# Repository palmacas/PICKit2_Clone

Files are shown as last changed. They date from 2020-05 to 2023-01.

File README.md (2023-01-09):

# PICKit2 Clone

PICKit2Clone

This is a DIY version (clone) of the well known Microchip's PICKit2 programmer, with an additional ZIF socket. The repository contains the editable EAGLE files and the scheme on PDF. In addition, the ZIF_Distribution folder contains images with the ICs and jumpers distribution on the ZIF socket depending on the PIC type.

---
More information:  
[PICKit 2 Clone Zócalo ZIF [Spanish]](https://palmacas.com/pickit-2-clone-zocalo-zif/)  
[Zócalo ZIF – PICKit 2 y PICKit 3 [Spanish]](https://palmacas.com/zocalo-zif-pickit-2-y-pickit-3/)  
[Distribución de Zócalo ZIF [Spanish]](https://palmacas.com/distribucion-zocalo-zif/)  
[PICKit 2 Clone ICSP [Spanish]](https://palmacas.com/pickit-2-clone-icsp/)

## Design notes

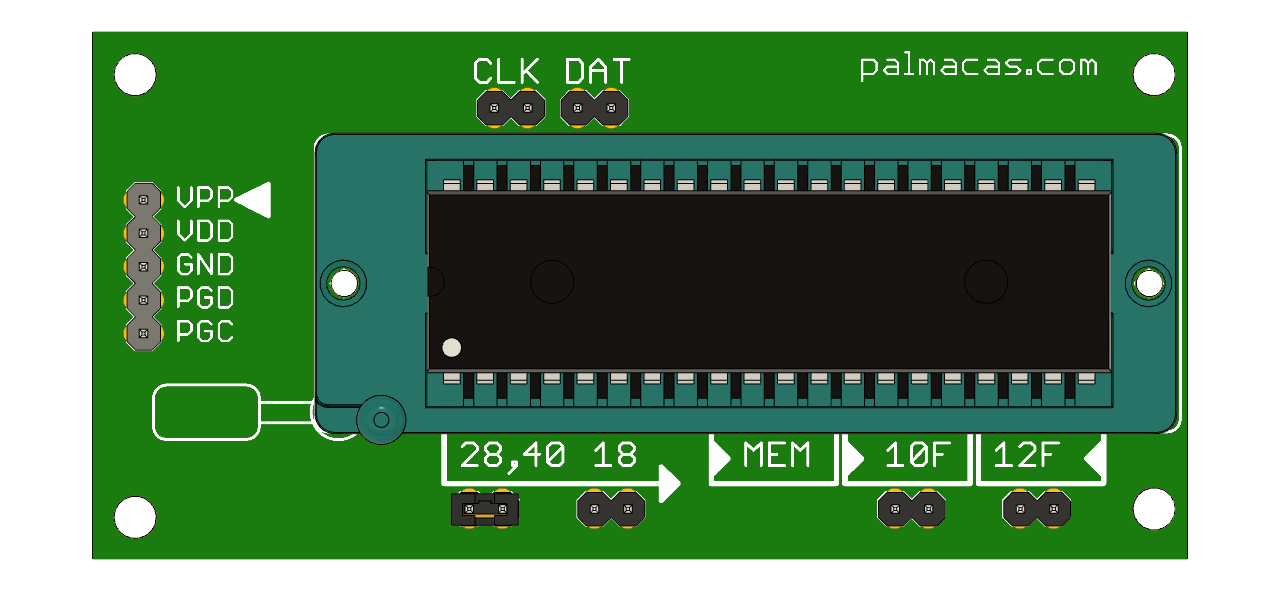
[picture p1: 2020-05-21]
ZIF_Distribution/40pin sdPIC.png

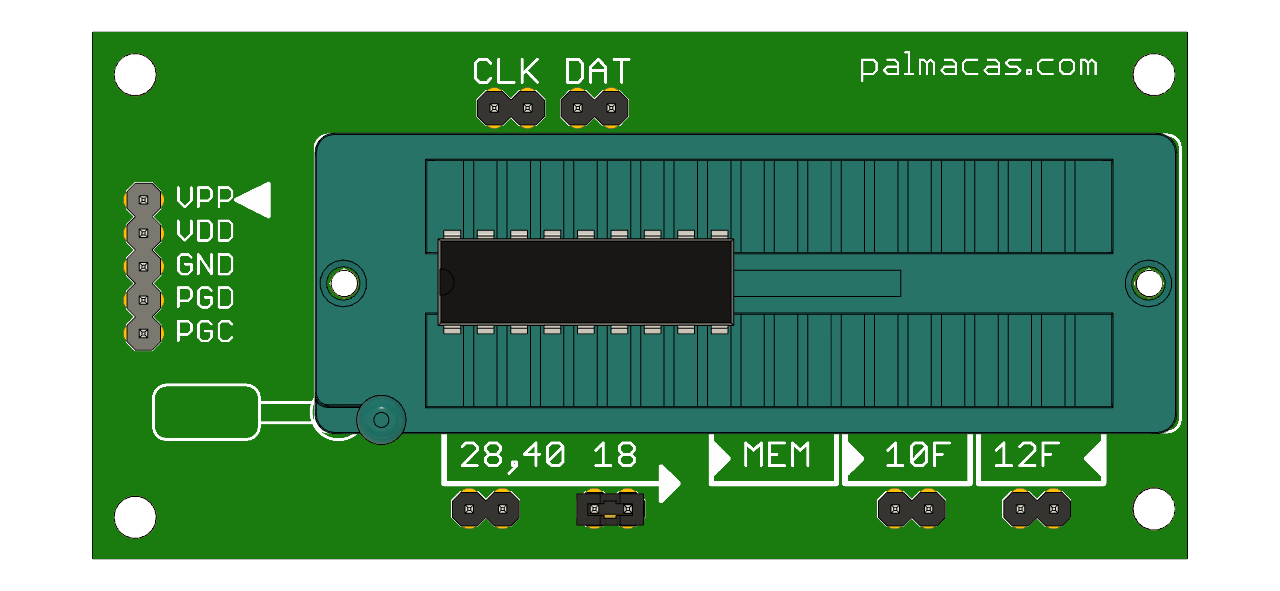
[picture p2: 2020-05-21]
ZIF_Distribution/18pin PIC.png

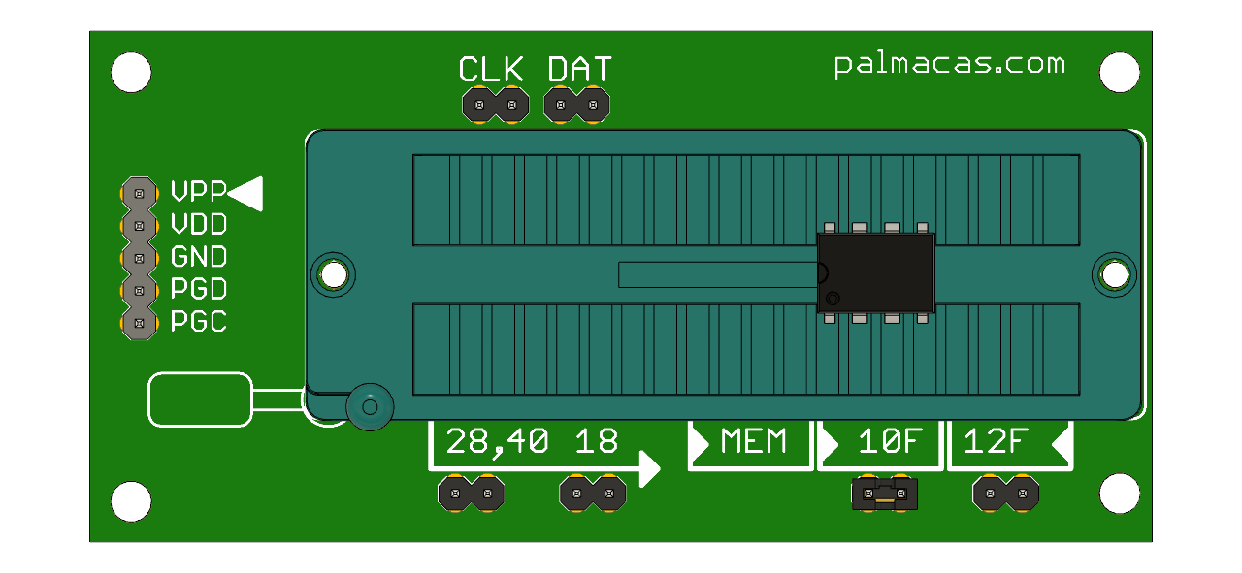
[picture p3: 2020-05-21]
ZIF_Distribution/8pin 10F PIC.png

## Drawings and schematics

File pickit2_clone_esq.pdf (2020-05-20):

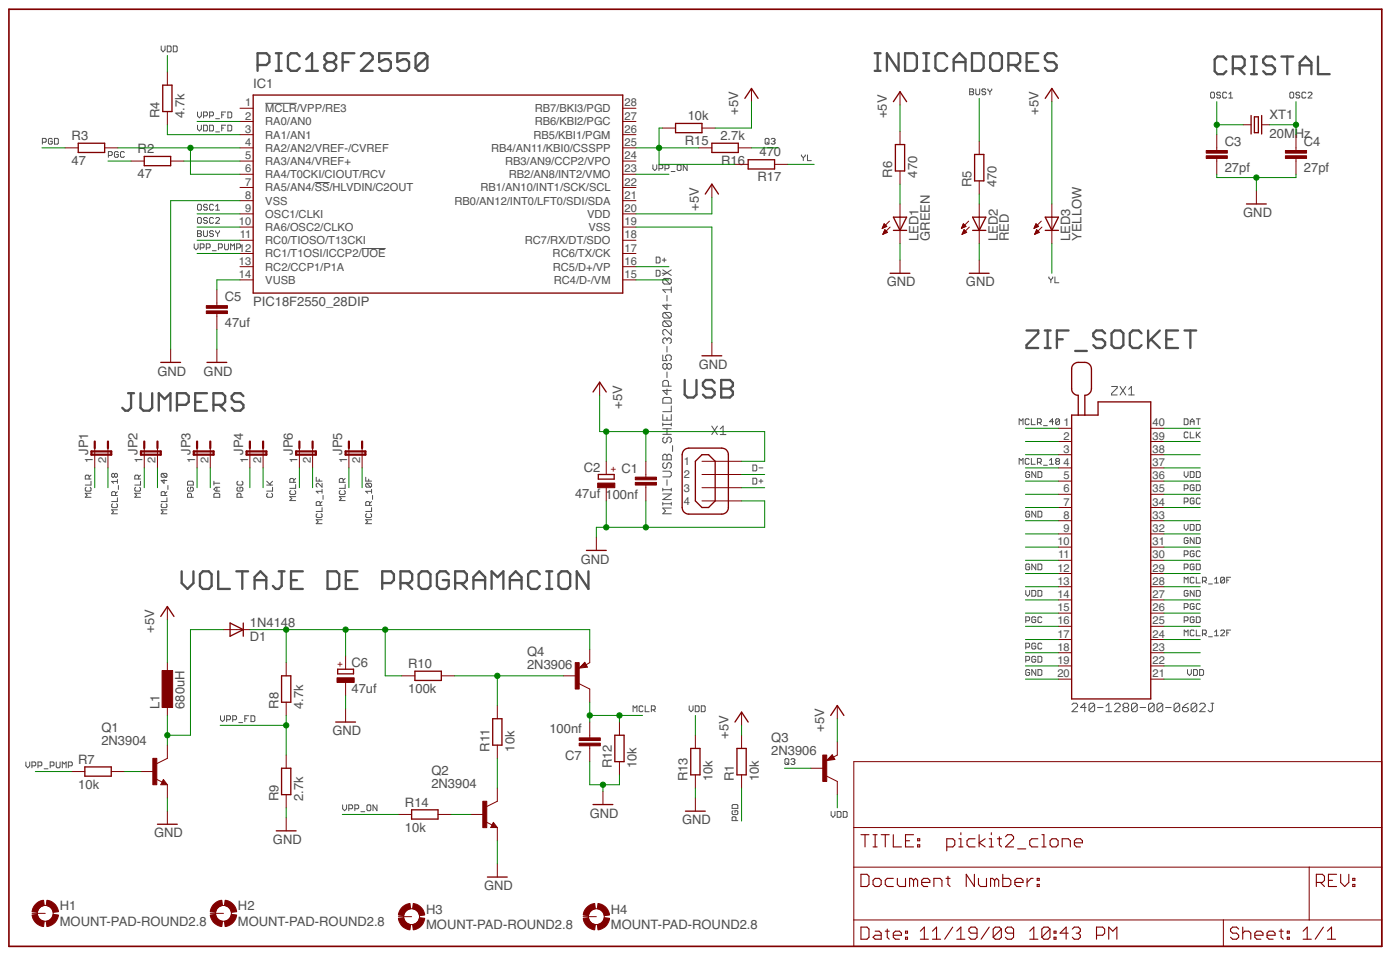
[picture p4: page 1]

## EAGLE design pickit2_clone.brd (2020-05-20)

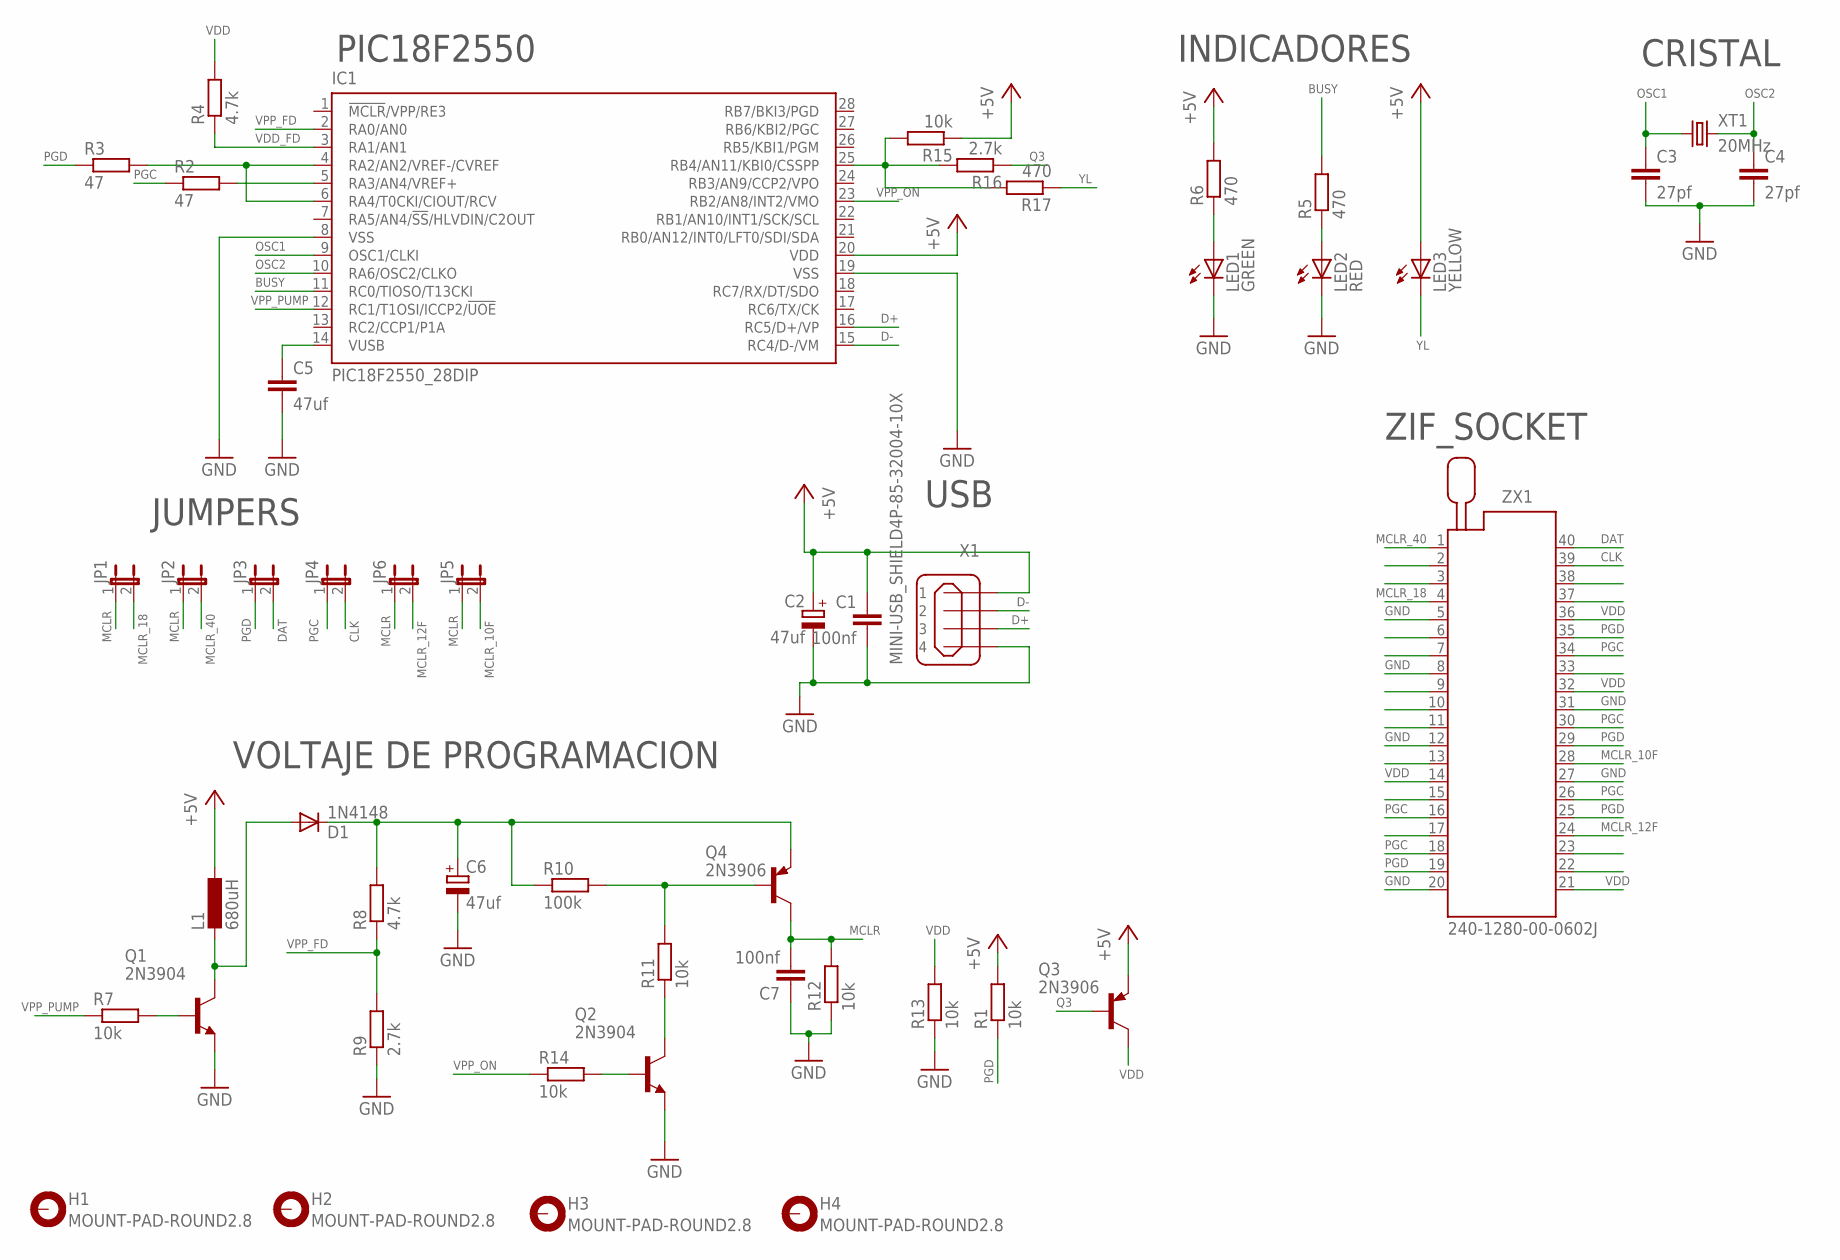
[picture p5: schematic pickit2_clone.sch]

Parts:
C1, C7: 100nf; C025-030X050
C2, C6: 47uf; E2-5
C3, C4: 27pf; C050-030X075
C5: 47uf; C050-030X075
D1: 1N4148; DO35-10
H1, H2, H3, H4: MOUNT-PAD-ROUND2.8; 2,8-PAD
IC1: PIC18F2550_28DIP; DIL28-3
JP1, JP2, JP3, JP4, JP5, JP6: JP1E; JP1
L1: 680uH; 0207/10
LED1: GREEN; LED5MM
LED2: RED; LED5MM
LED3: YELLOW; LED5MM
Q1, Q2: 2N3904; TO92-EBC
Q3, Q4: 2N3906; TO92-CBE
R1, R7, R11, R12, R13, R14, R15: 10k; 0207/7
R2, R3: 47; 0207/7
R4, R8: 4.7k; 0207/7
R5, R6, R17: 470; 0207/7
R9, R16: 2.7k; 0207/7
R10: 100k; 0207/7
X1: MINI-USB_SHIELD4P-85-32004-10X; 85-32004-10X
XT1: 20MHz; HC49/S
ZX1: 240-1280-00-0602J

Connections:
+5V: C1.1, C2.+, IC1.20 (VDD), L1.1, LED3.A, Q3.E, R1.2, R6.2, R15.1, X1.1
BUSY: IC1.11 (RC0/TIOSO/T13CKI), R5.2
CLK: JP4.2, ZX1.39
D+: IC1.16 (RC5/D+/VP), X1.3
D-: IC1.15 (RC4/D-/VM), X1.2
DAT: JP3.2, ZX1.40
GND: C1.2, C2.-, C3.2, C4.2, C5.2, C6.-, C7.1, IC1.8 (VSS), IC1.19 (VSS), LED1.K (C), LED2.K (C), Q1.E, Q2.E, R9.1, R12.1, R13.1, X1.4, ZX1.5, ZX1.8, ZX1.12, ZX1.20, ZX1.27, ZX1.31
MCLR: C7.2, JP1.1, JP2.1, JP5.1, JP6.1, Q4.C, R12.2
MCLR_10F: JP5.2, ZX1.28
MCLR_12F: JP6.2, ZX1.24
MCLR_18: JP1.2, ZX1.4
MCLR_40: JP2.2, ZX1.1
unnamed: C5.1, IC1.14 (VUSB)
unnamed: LED1.A, R6.1
unnamed: IC1.4 (RA2/AN2/VREF-/CVREF), IC1.6 (RA4/T0CKI/CIOUT/RCV), R3.2
unnamed: Q1.B, R7.2
unnamed: IC1.5 (RA3/AN4/VREF+), R2.2
unnamed: LED2.A, R5.1
unnamed: C6.+, D1.C, Q4.E, R8.2, R10.1
unnamed: Q4.B, R10.2, R11.2
unnamed: IC1.25 (RB4/AN11/KBI0/CSSPP), R15.2, R16.2, R17.2
unnamed: Q2.C, R11.1
unnamed: Q2.B, R14.2
unnamed: D1.A, L1.2, Q1.C
OSC1: C3.1, IC1.9 (OSC1/CLKI), XT1.1
OSC2: C4.1, IC1.10 (RA6/OSC2/CLKO), XT1.2
PGC: JP4.1, R2.1, ZX1.16, ZX1.18, ZX1.26, ZX1.30, ZX1.34
PGD: JP3.1, R1.1, R3.1, ZX1.19, ZX1.25, ZX1.29, ZX1.35
Q3: Q3.B, R16.1
VDD: Q3.C, R4.2, R13.2, ZX1.14, ZX1.21, ZX1.32, ZX1.36
VDD_FD: IC1.3 (RA1/AN1), R4.1
VPP_FD: IC1.2 (RA0/AN0), R8.1, R9.2
VPP_ON: IC1.23 (RB2/AN8/INT2/VMO), R14.1
VPP_PUMP: IC1.12 (RC1/T1OSI/ICCP2/!UOE), R7.1
YL: LED3.K (C), R17.1

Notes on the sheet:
PIC18F2550
INDICADORES
USB
ZIF_SOCKET
VOLTAJE DE PROGRAMACION
CRISTAL
JUMPERS

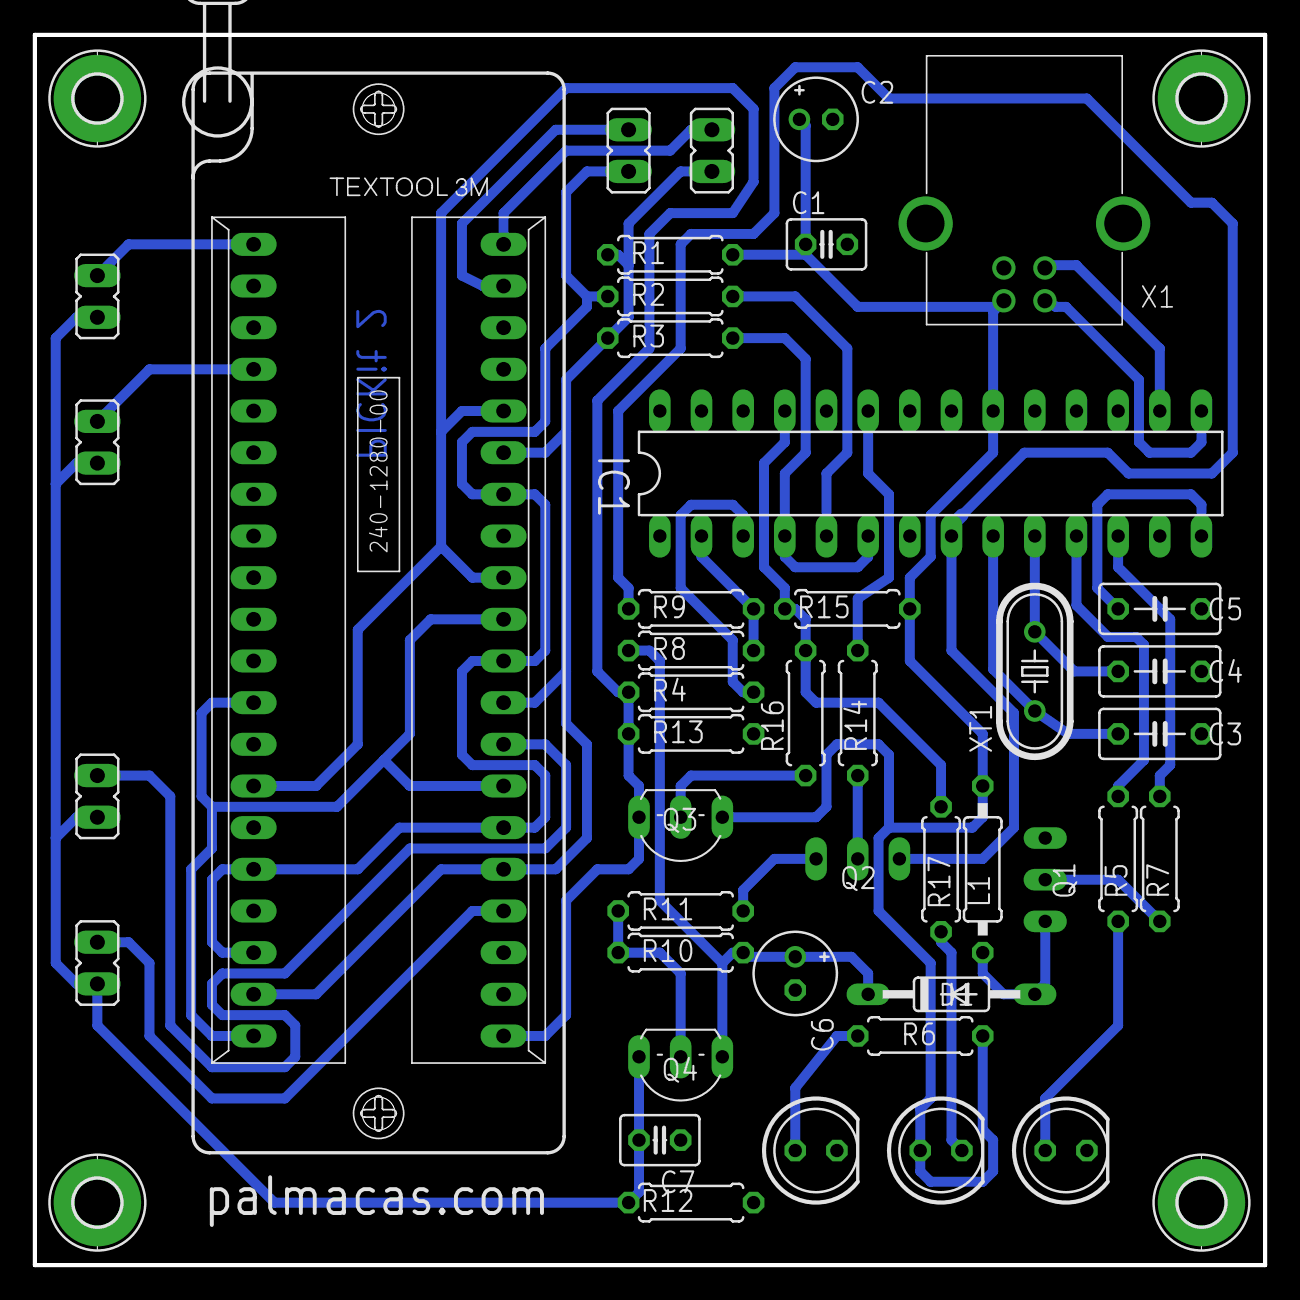
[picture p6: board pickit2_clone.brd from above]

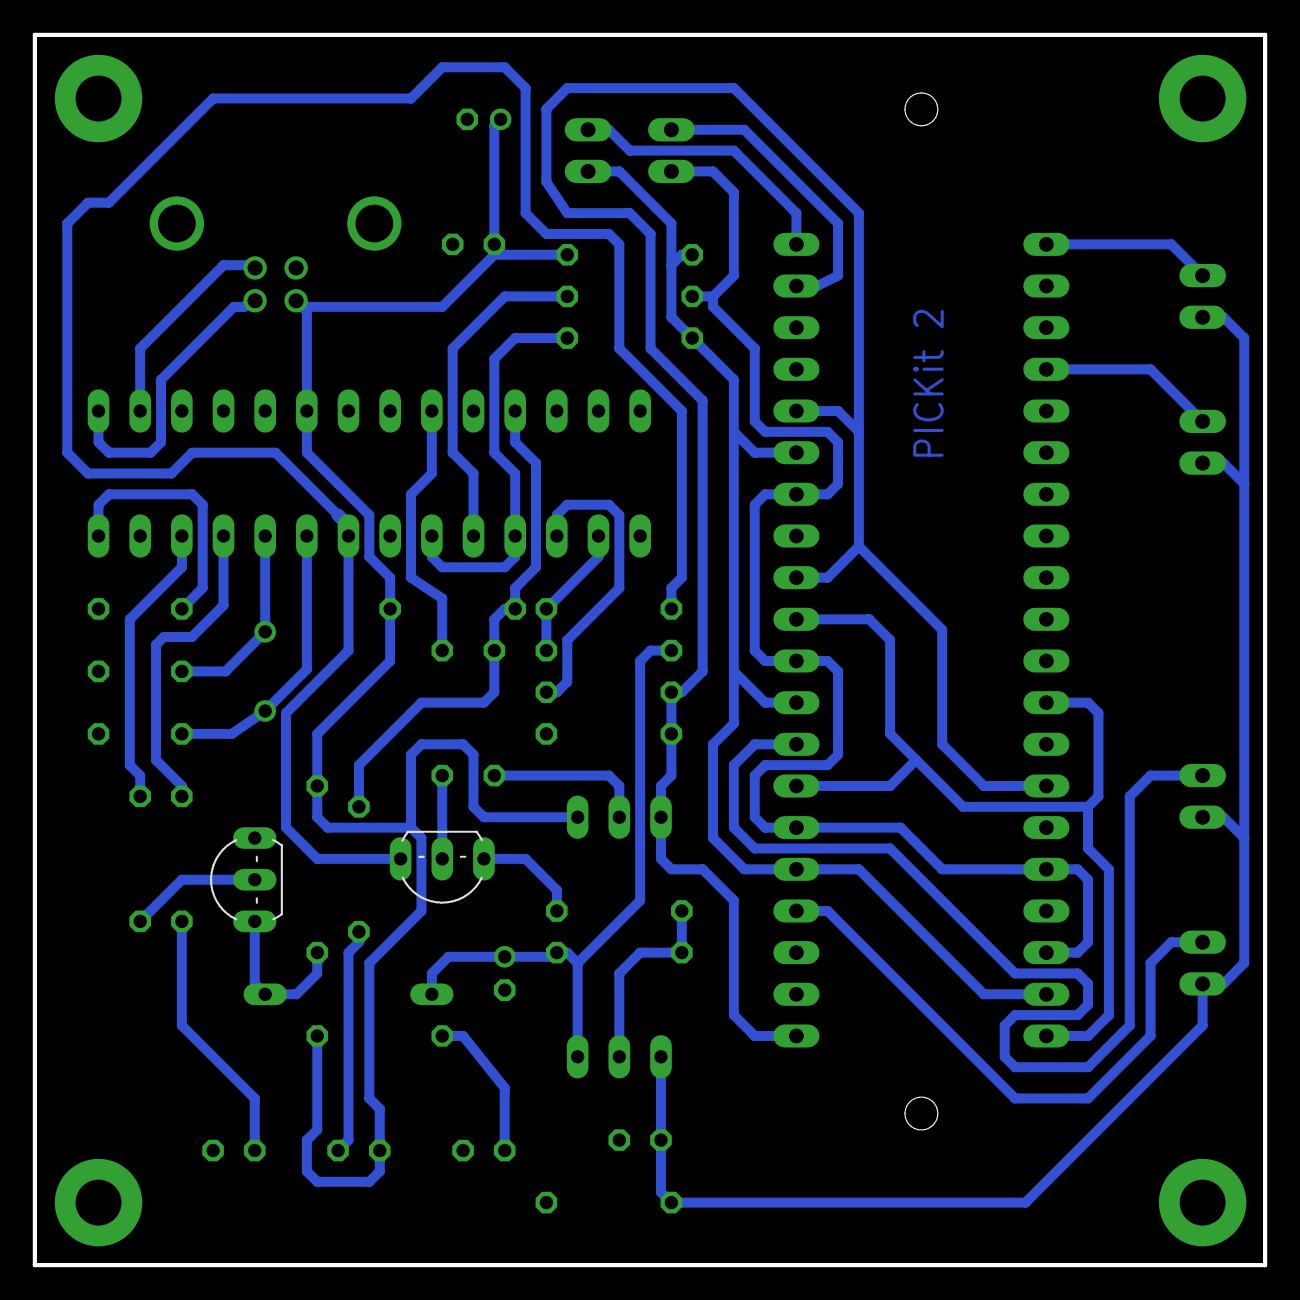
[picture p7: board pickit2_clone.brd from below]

Board: 2 copper layers, 75.0 x 75.0 mm, 47 parts (2 on the bottom side), 35 nets.
